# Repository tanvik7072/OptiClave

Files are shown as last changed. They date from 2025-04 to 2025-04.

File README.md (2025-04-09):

# **OptiClave**
At OptiClave we aim to provide to tackle the problem to microscopy within tissue hoods by providing a simple to assemble, open-source and autoclavable microscope that can accurately image inside a tissue hood.  

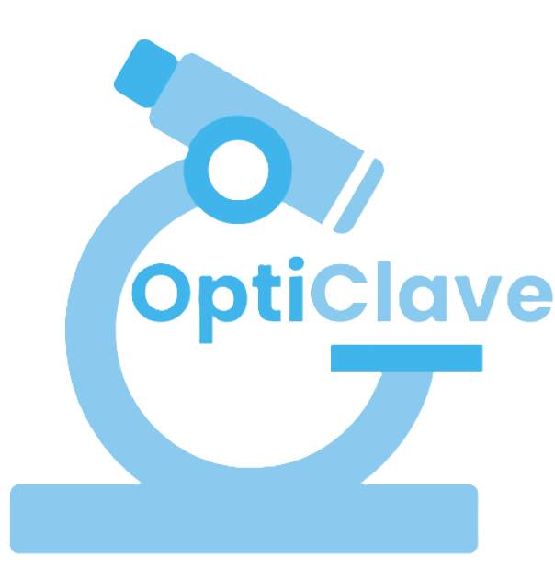
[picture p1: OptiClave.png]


## Printing
The STL files for OptiClave can be found in this repository.  
[STLs](STLs)

We recommend the use of SLA printing with a specific type of autoclavable resin, explained further below.  

Using other types of 3D printing or materials may cause damage during autoclaving.  

<p align="center">
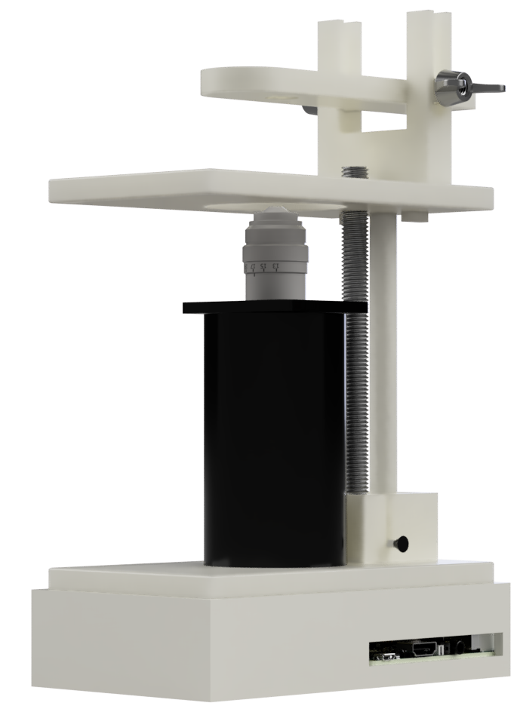
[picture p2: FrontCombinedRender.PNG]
  
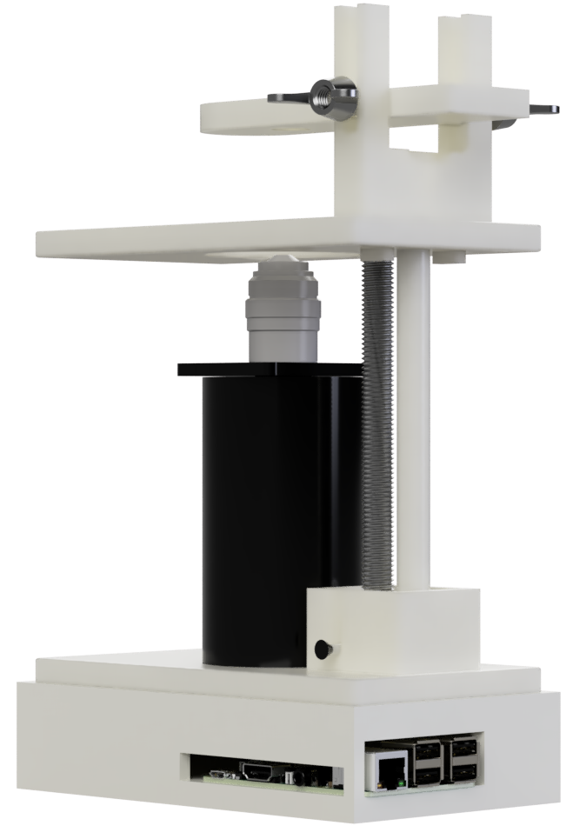
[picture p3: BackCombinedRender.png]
  
</p>

## Materials

To print the microscope, a biocompatible, autoclavable resin (such as LiqCreate Biocompatible Resin) is recommended. Liqcreate maintains high flexural strength and modulus even after autoclaving at 121°C and 134°C, making it the best candidate for sterilisable 3D-printed tissue culture components. Although slightly more expensive, the cost per print is not significantly higher, making it an optimal choice in terms of both performance and affordability.

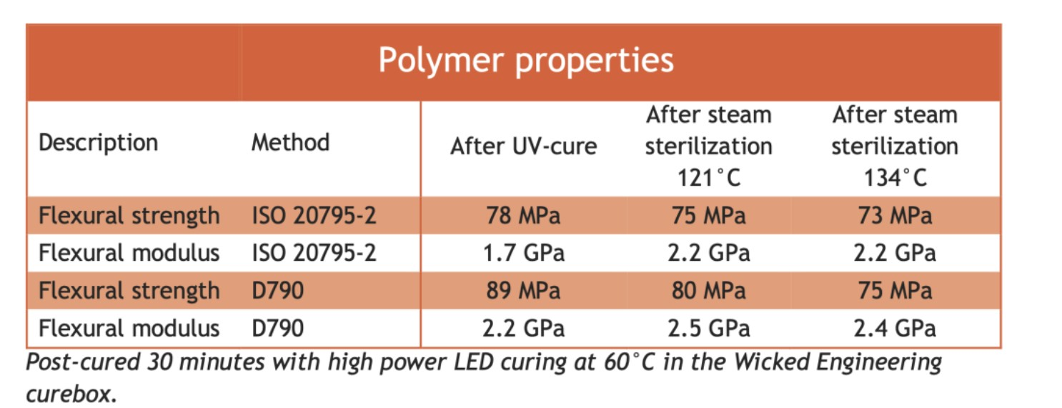
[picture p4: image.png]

[https://www.liqcreate.com/biocompatible-dlp-lcd-sla-3dprinting-resin/]

## Assembly

An assembly video is provided within this repository:  

The Raspberry Pi is placed into the electronics box, aligning the ports with the gaps as seen in the video and the lid is placed on top.  

The threaded rod is to have its gear screwed onto the bottom and placed into the gear box alongside the stable rod.  

The specimen platform can be pushed onto the stop of the rods, acting as a cantilever while the LED holder is assembled on top.  

Finally, the objective is screwed into the optics tube and attached using the twist and lock mechanism using the protusions at its base.  

A video render of the assembly can be seen below.  

[Assembly Video](Assembly.avi)

## Wiring
The wiring for OptiClave is fairly simple:  

Connect pin 11 and the ground to the white LED in the cantilever.  

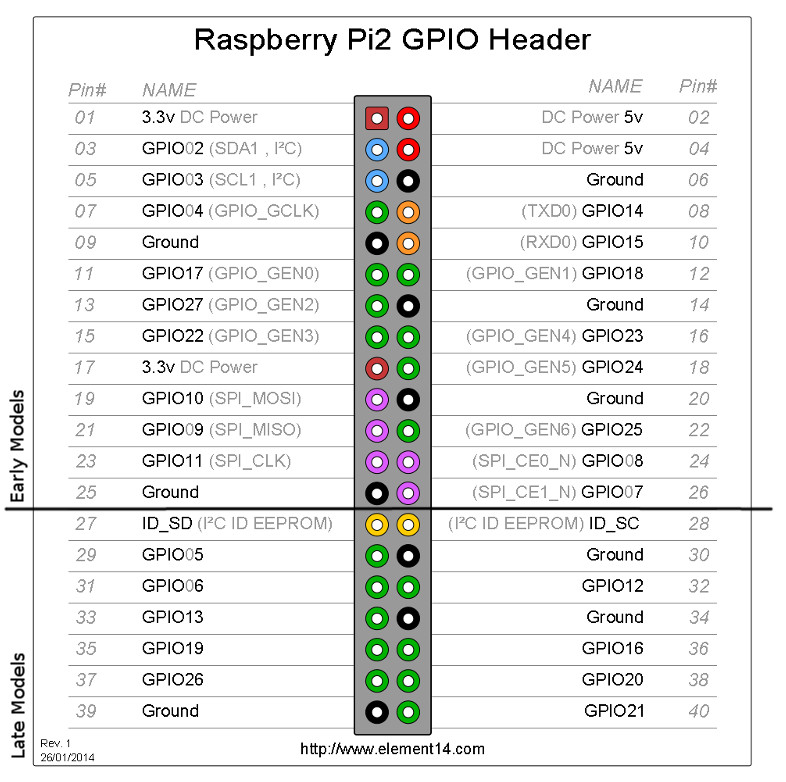
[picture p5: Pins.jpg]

[SparkFun Pi GPIO Guide](https://learn.sparkfun.com/tutorials/raspberry-gpio/gpio-pinout)  

The Pi camera should be attatched via ribbon to the Pi board and slotted through the hole in the botton of the microscope to be clipped into the optics tube.  

Ensure all wires are kept outside of the cameras field of view and are removed before autoclaving.  

Electronics should be steralised using less aggressive techniques, ideally isopropyl alcohol.  

## Programming
OptiClave comes with prewritten Python to work

Install the correct dependencies:
#### PiCamera2 (for camera control)
```
sudo apt update
sudo apt install python3-picamera2
```

#### OpenCV (image processing/display)

```
sudo apt install python3-opencv
```

#### RPi.GPIO (for GPIO control)

```
sudo apt install python3-rpi.gpio
```

### Running the script
Save the script into the pi using

```
git add https://github.com/tanvik7072/OptiClave
```

Make it executable:

```
chmod +x PiCamera.py
```

Run it:

```
python3 PiCamera.py
```

## Usage

Once setup and the Python script is running, a window should appear showing the view of the camera. Place a sample above the cameraon the platform and use this to adjust the focus of the microscope until a clear image can be seen.  

Within the console:  
Press S to take a screenshot  
Press Q to quit

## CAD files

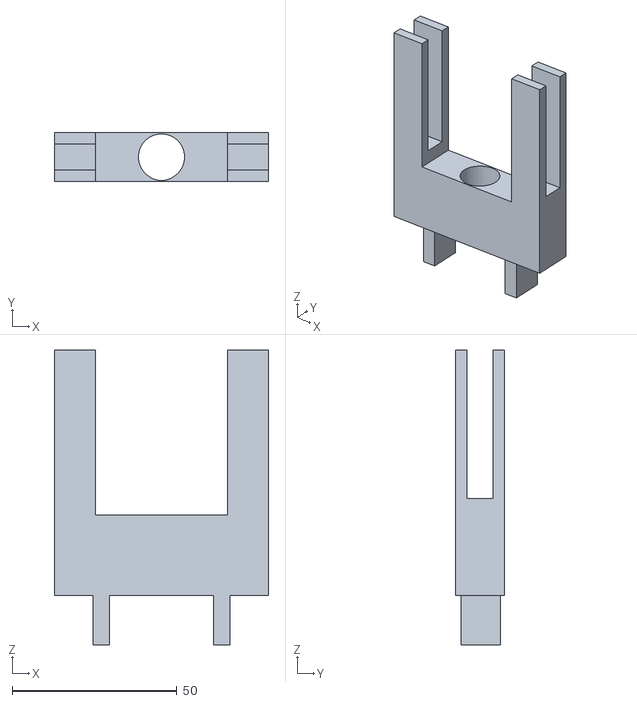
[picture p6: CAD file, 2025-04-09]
STLs/LED+Base.stl
65.0 x 15.0 x 89.5

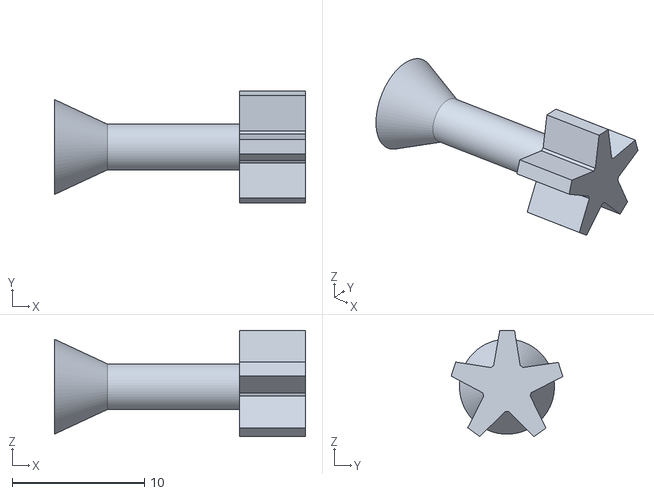
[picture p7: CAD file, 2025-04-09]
STLs/Fine+Gear.stl
19.0 x 8.46 x 8.05

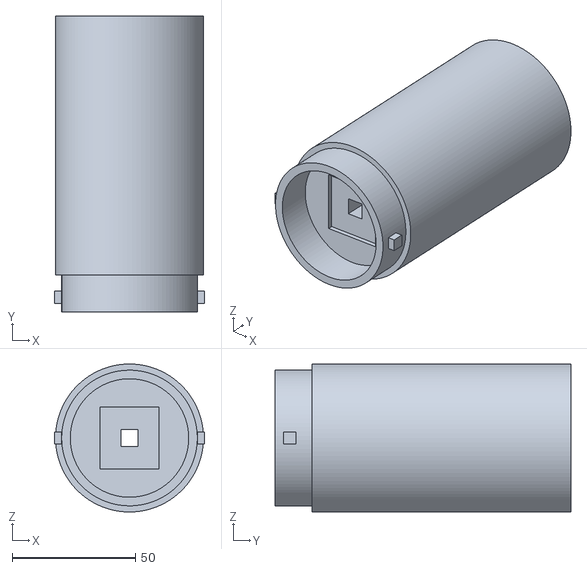
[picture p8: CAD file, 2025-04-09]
STLs/optics_tube.stl
61.0 x 120.0 x 60.0

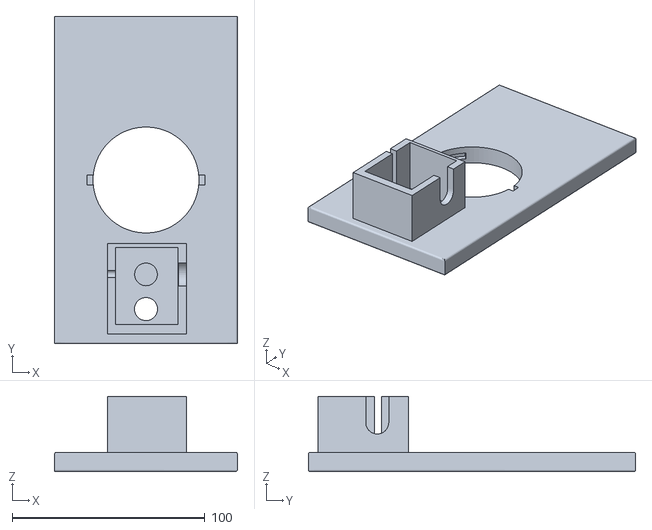
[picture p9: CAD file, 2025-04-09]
STLs/Electronics+Tray.stl
95.0 x 170.0 x 39.0

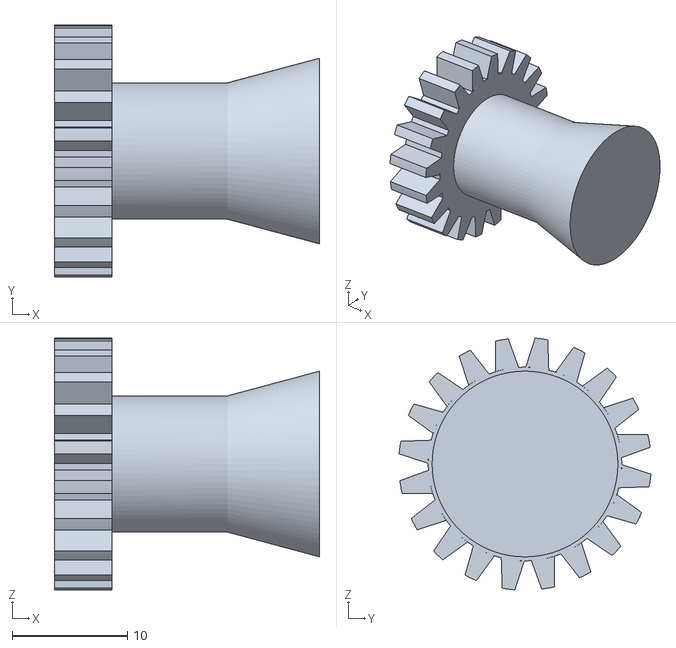
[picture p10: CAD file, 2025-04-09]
STLs/Coarse+Gear.stl
23.0 x 21.9 x 21.9

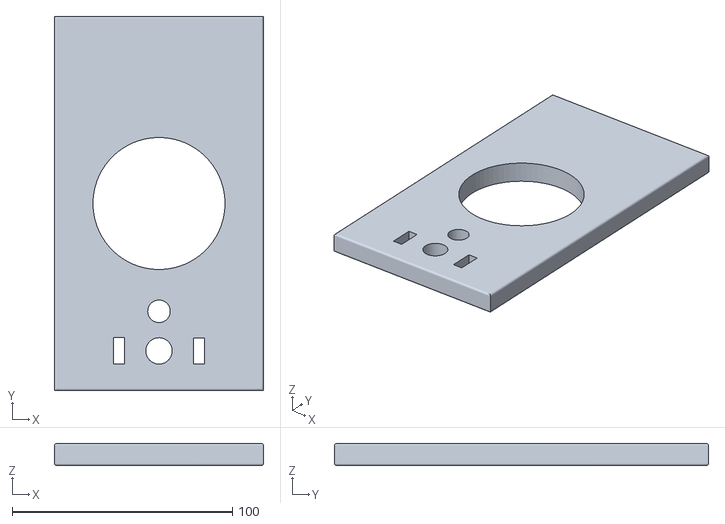
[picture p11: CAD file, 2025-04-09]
STLs/Platform.stl
95.0 x 170.0 x 10.0

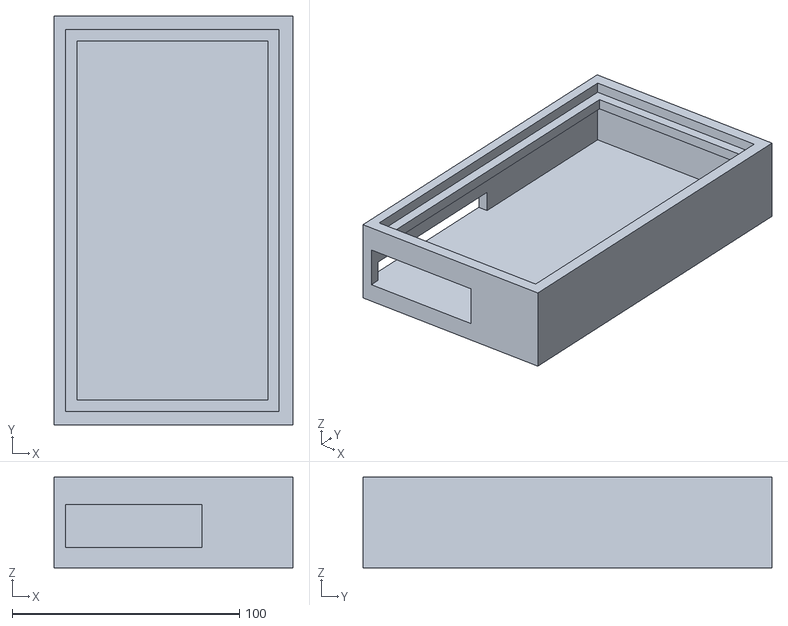
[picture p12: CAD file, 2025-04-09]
STLs/Staging_PiCasing.stl
105.0 x 180.0 x 40.0

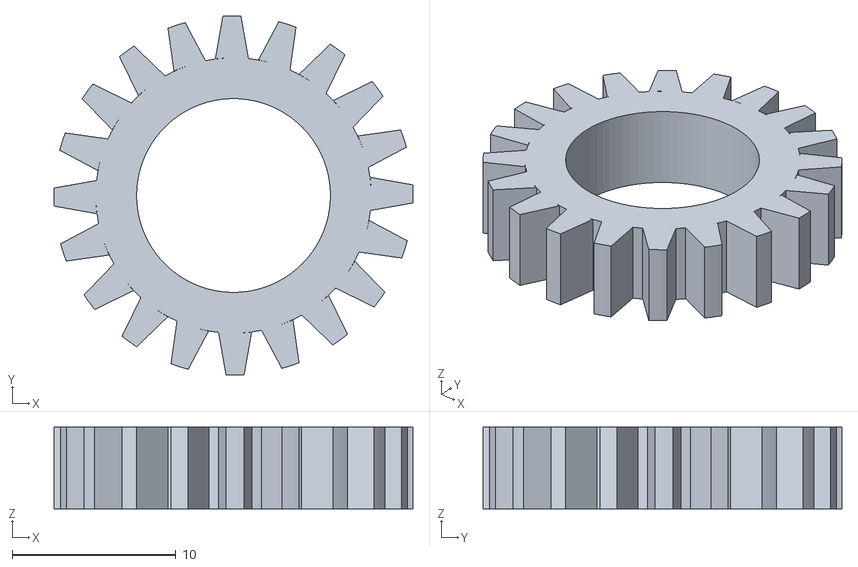
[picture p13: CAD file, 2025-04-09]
STLs/Rod+Gear.stl
21.9 x 21.9 x 5.00

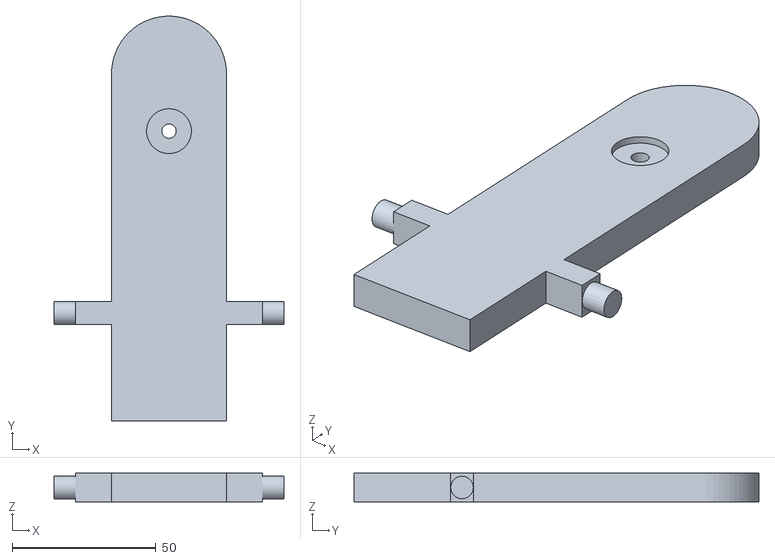
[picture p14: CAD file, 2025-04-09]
STLs/LED+Cantilever.stl
80.0 x 140.7 x 10.0

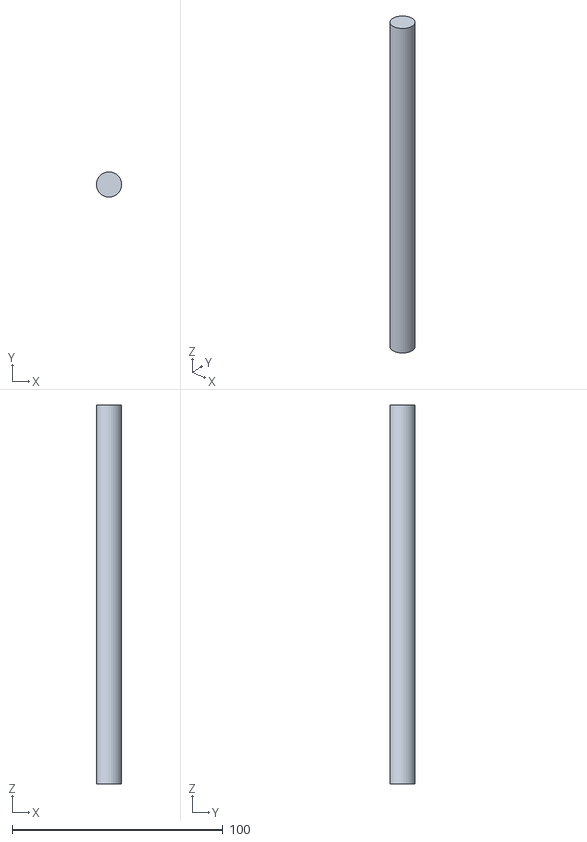
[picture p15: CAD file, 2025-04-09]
STLs/Stable+Rod.stl
12.0 x 12.0 x 180.0

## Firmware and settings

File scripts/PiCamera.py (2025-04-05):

# -*- coding: utf-8 -*-
"""
@author: Calum Robertson - Opticlave
2025

This is an open source script for use with the 
Opticlave microscope on a Raspberry pi with 
camera module 3

"""

import time
import cv2
import RPi.GPIO as GPIO
from picamera2 import Picamera2

#GPIO pin 17 on RPi
LED_PIN = 17 

def RunCamera():
    #Initialising

     # --- GPIO SETUP ---
    GPIO.setmode(GPIO.BCM)  
    GPIO.setup(LED_PIN, GPIO.OUT, initial=GPIO.LOW)

    
    # --- CAMERA SETUP ---
    picam2 = Picamera2()
    preview_config = picam2.create_preview_configuration({"size": (640, 480)})
    picam2.configure(preview_config)
    picam2.start()

    #Turn LED on
    GPIO.output(LED_PIN, GPIO.HIGH)
    
    print("Press 's' to take a screenshot, 'q' to quit.\n")
    
    while True:
        
        frame = picam2.capture_array()
        
        cv2.imshow("Camera Preview",frame)
        
        key = cv2.waitKey(1) & 0xFF

        #User controls
        #Screenshot
        if key == ord('s'):
            timestamp = time.strftime("%Y%m%d_%H%M%S")
            filename = f"screenshot_{timestamp}.jpg"   
            
            cv2.imwrite(filename,frame)
            print(f"Screenshot saved: {filename}\n")
            print("Press 's' to take a screenshot, 'q' to quit.\n")

        #Quit
        elif key == ord('q'):
            
            break
    
    #Clean up    
    GPIO.output(LED_PIN, GPIO.LOW)
    cv2.destroyAllWindows()
    picam2.close()
    GPIO.cleanup()


if __name__ == "__main__":
    RunCamera()

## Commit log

2025-04-05 Initial commit
    Python script to open and view the Raspberry Pi Camera Module 3 on a Raspberry Pi
2025-04-05 Added LED through GPIO
2025-04-05 Defined GPIO Pin
2025-04-05 Assembly video
2025-04-07 Update README.md
    Updated materials information
2025-04-07 Material properties added
    LiqCreate biocompatible resin material properties added.
2025-04-07 Update README.md
    Updated material properties table
2025-04-07 Update README.md
    Added source to material properties table
2025-04-09 Large assembly file
